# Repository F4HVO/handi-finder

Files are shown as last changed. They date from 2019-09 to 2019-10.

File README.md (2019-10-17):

# handi-finder
F4HVO implementation of Handi Finder.

This circuit was made in a hurry but fortunately it works.

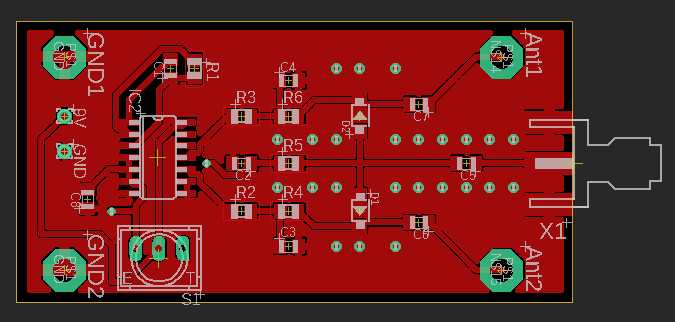
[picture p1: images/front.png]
Board


## How to make it

- Send the gerber files to your favorite PCB factory (OSH Park, Elecrow, AllPCB, ...).
- Get the components (see BOM below)
- Assemble (hot air station or reflow oven recommended, but a frying pan and sand can do the trick)
- Then add antennas : rigid wire of 48cm on each side, between ANT1 and ANT1GND (and ANT2-ANT2GND respectively). Make a bow shape by bending the wire to form 3 edges (two of 17cm and one of 12cm).
- Have fun.

## BOM
All capacitors and resistors are 0805.

- U1 : CD4047 (smd version)
- C1 : 0.2 uF
- C2, C3, C4, C5, C6, C7 : 1nF
- C8 : 0.1 uF
- R1, R2, R3 : 10k
- D1, D2 : 1n4148 (or any switching diode, or PIN diode)
- Switch : good luck, or no switch
- SMA connector
- 9V battery (and connector)

## Remarks

- The switch package is unfamiliar, a more standard one might be better. I did not use a switch, I soldered a jumper on my assembled board.

## Release notes

### Version 1.1 :
- Change diodes package to SOD 123
- Change hole diameter to 2.6mm

### Version 1.2 :
- Fix switch connection, CD4047 was always powered on.

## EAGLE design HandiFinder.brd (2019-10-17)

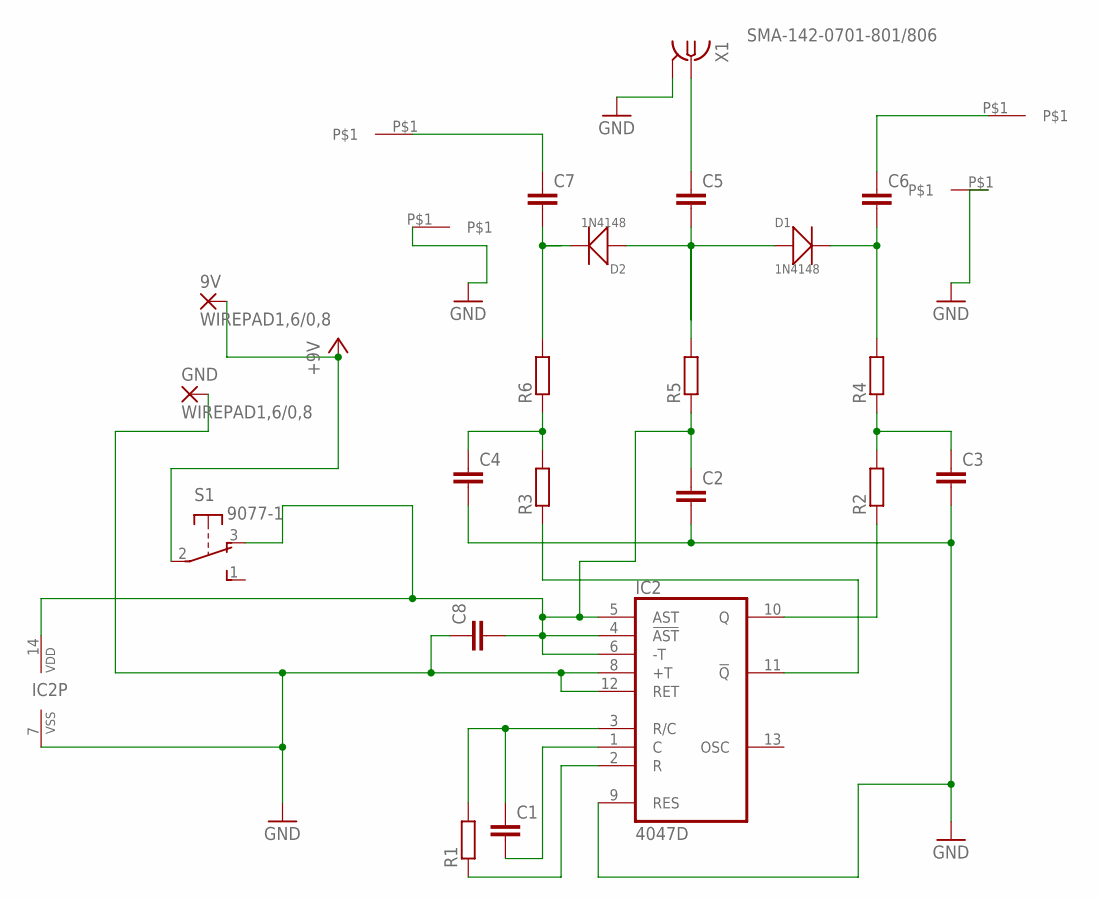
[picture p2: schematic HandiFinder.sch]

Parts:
9V: WIREPAD1,6/0,8; 1,6/0,8
ANT1: ANT12; 2.6MMHOLE
ANT1GND2, ANT2GND2, ANT22: WIREPAD; 2.6MMHOLE
C1, C2, C3, C4, C5, C6, C7, C8: C-EUC0805K; C0805K
D1, D2: 1N4148; SOD-123
GND: WIREPAD1,6/0,8; 1,6/0,8
IC2: 4047D; SO14
R1, R2, R3, R4, R5, R6: R-EU_R0805; R0805
S1: 9077-1
X1: SMA-142-0701-801/806; J502-ND-142-0701-801/806

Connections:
+5V: 9V.1, S1.2
GND: ANT1GND2.P$1, ANT2GND2.P$1, C2.2, C3.2, C4.2, C8.1, GND.1, IC2.7 (VSS), IC2.8 (+T), IC2.9 (RES), IC2.12 (RET), X1.G@1 (2), X1.G@2 (2), X1.G@3 (2), X1.G@4 (2)
unnamed: C1.1, IC2.3 (R/C), R1.2
unnamed: C1.2, IC2.1 (C)
unnamed: IC2.2 (R), R1.1
unnamed: C7.2, D2.-, R6.2
unnamed: C3.1, R2.2, R4.1
unnamed: C5.1, X1.1
unnamed: C4.1, R3.2, R6.1
unnamed: IC2.11 (!Q), R3.1
unnamed: IC2.10 (Q), R2.1
unnamed: C5.2, D1.+, D2.+, R5.2
unnamed: C6.2, D1.-, R4.2
unnamed: ANT1.P$1, C7.1
unnamed: ANT22.P$1, C6.1
unnamed: C2.1, C8.2, IC2.4 (!AST), IC2.5 (AST), IC2.6 (-T), IC2.14 (VDD), R5.1, S1.3 (O)

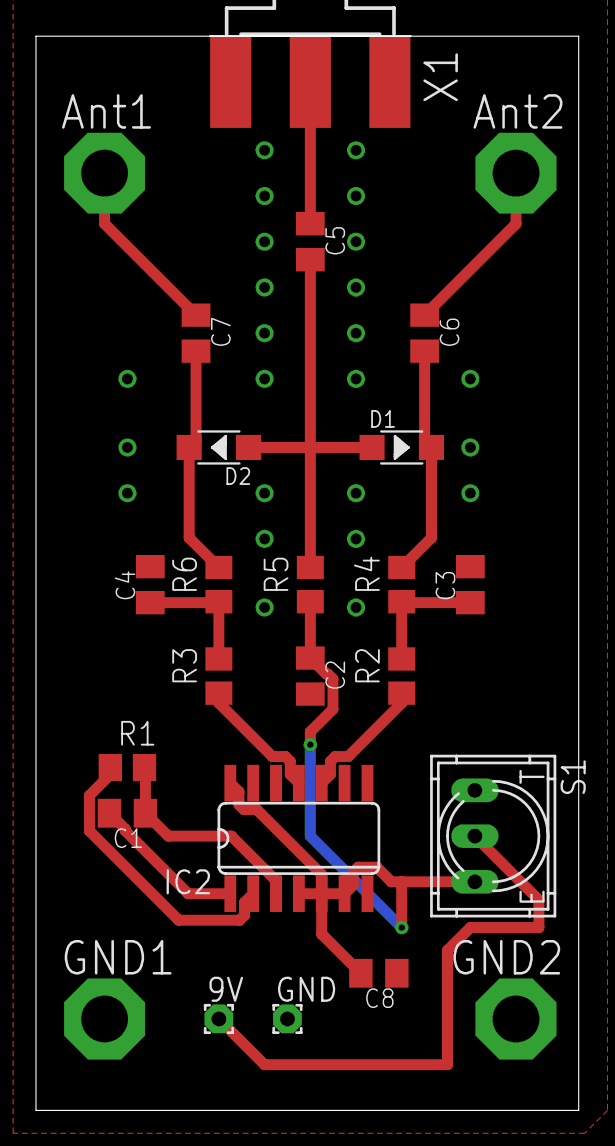
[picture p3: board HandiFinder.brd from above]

Board: 2 copper layers, 30.1 x 59.7 mm, 25 parts (0 on the bottom side), 16 nets.

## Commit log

2019-09-03 Initial file import.
    [HandiFinder.brd, HandiFinder.sch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]
2019-09-03 Rotate image of board
2019-09-03 Remove unused file Switch.lbr
2019-09-10 Change hole diameter to 2.6mm to allow 2.5mm screw. Change diode footprint to SOD 123.
    [HandiFinder.brd, HandiFinder.sch]
2019-09-10 Extend wirepad. Add gerber files.
    [HandiFinder.brd, HandiFinder.sch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]
2019-09-11 Update board image for v1.1
2019-10-17 Fix switch misconnection.
    [HandiFinder.brd, HandiFinder.sch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]
